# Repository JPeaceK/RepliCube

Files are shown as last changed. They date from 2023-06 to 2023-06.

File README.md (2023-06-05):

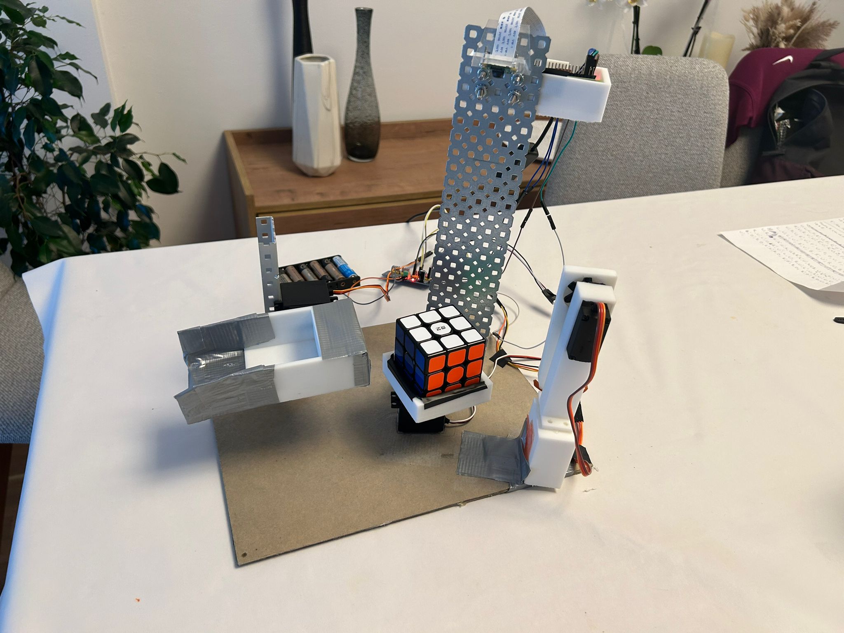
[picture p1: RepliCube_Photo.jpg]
Replicube

# Table of Contents
   * [What is this?](#what-is-this)
   * [Our main goal](#our-main-goal)
   * [Requirements](#requirements)
   * [Documentation](#documentation)
   * [Hardware Structure](hardware-structure)
   * [Software Architecture](software-architecture)
   * [Images](#images)
   * [3D](#3d)
   * [Video](#video)
   * [Special thanks](#special-thanks)
   * [Authors](#authors)

# What is this?
RepliCube is a robot that solves and replicates Rubik Cubes. This robot is equipped with advanced computer vision capabilities that enable it to solve a Rubik's Cube and replicate the pattern of another cube with high accuracy. The robot utilizes a camera to scan and capture the configuration of a Rubik's Cube, which is then stored in its memory for further processing. 

# Our main goal
  
We are a group of 4 students currently studying Computer Engineering at the Universitat Autònoma de Barcelona.  This project is part of a subject called Robòtica, Llenguatge i Programació (RLP), where we are tasked with creating a robot using Agile methods. And our main goal is to bring our 3-month project to life. 

That being said, we hope you enjoy our little project. 

# Requirements
For running code:
 - [Python 3.11.x](https://www.python.org/)

For development:
 - [We used PyCharm](https://www.jetbrains.com/es-es/pycharm/)

# Documentation
All the documentation that might be useful, like servo motors guides, Hardware Structure, or Software Architecture are provided in this repository. The directories that contain this files are named:

 - [Hardware](https://github.com/JPeaceK/RepliCube/tree/main/Hardware)
 - [Software]()
 - [Manual de Fabricantes](https://github.com/JPeaceK/RepliCube/tree/main/Manuales%20de%20Fabricantes)

You can also see the references of the [Hardware Structure](hardware-structure) and the [Software Architecture](software-architecture) in this README.md file.

It is also provided a report that contains all development procedures named "Replicube Report".

# Hardware Structure
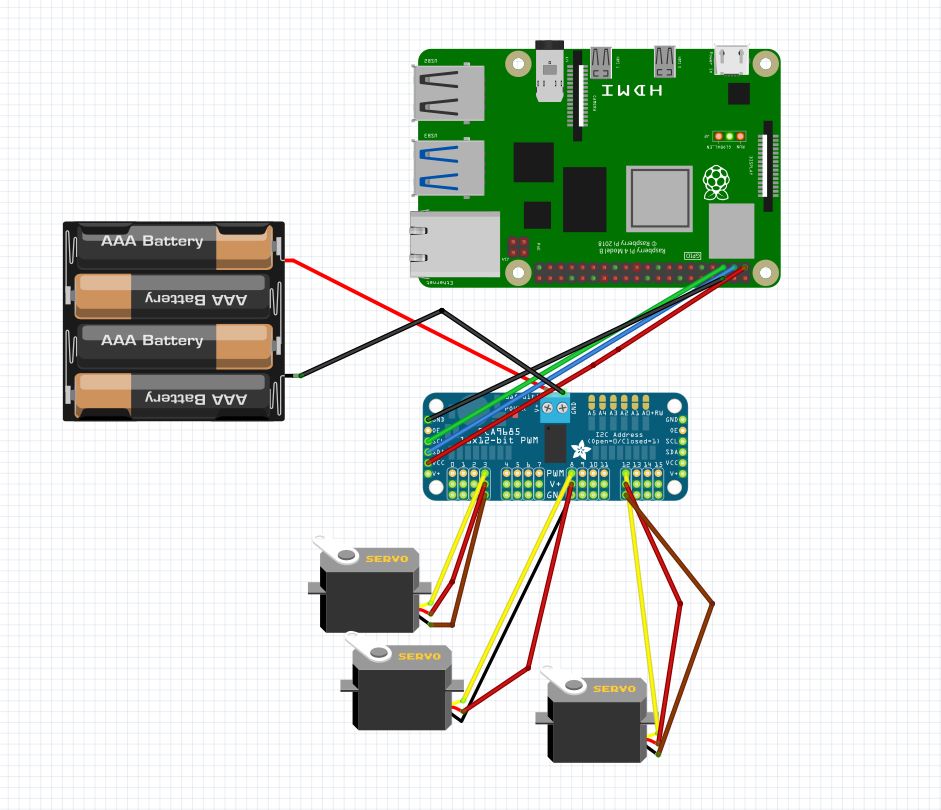
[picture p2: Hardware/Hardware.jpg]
Hardware Structure


# Software Architecture
The software Architecture is the following:
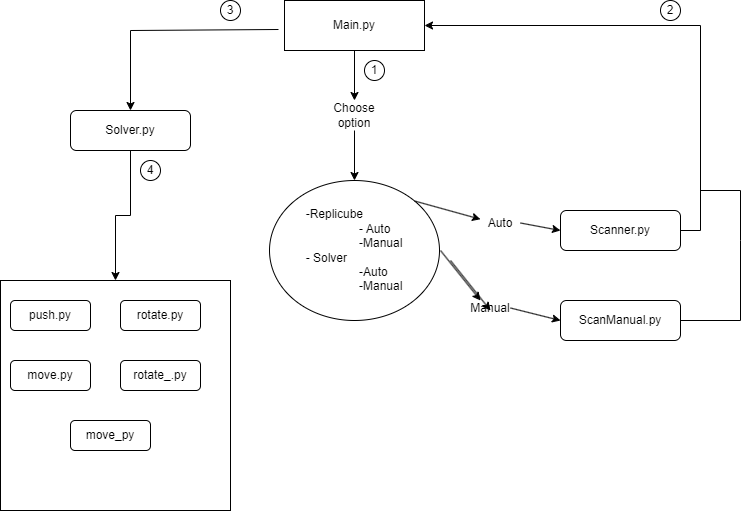
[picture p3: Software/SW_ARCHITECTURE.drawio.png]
Software Structure


And here a Flux Diagram of the code:
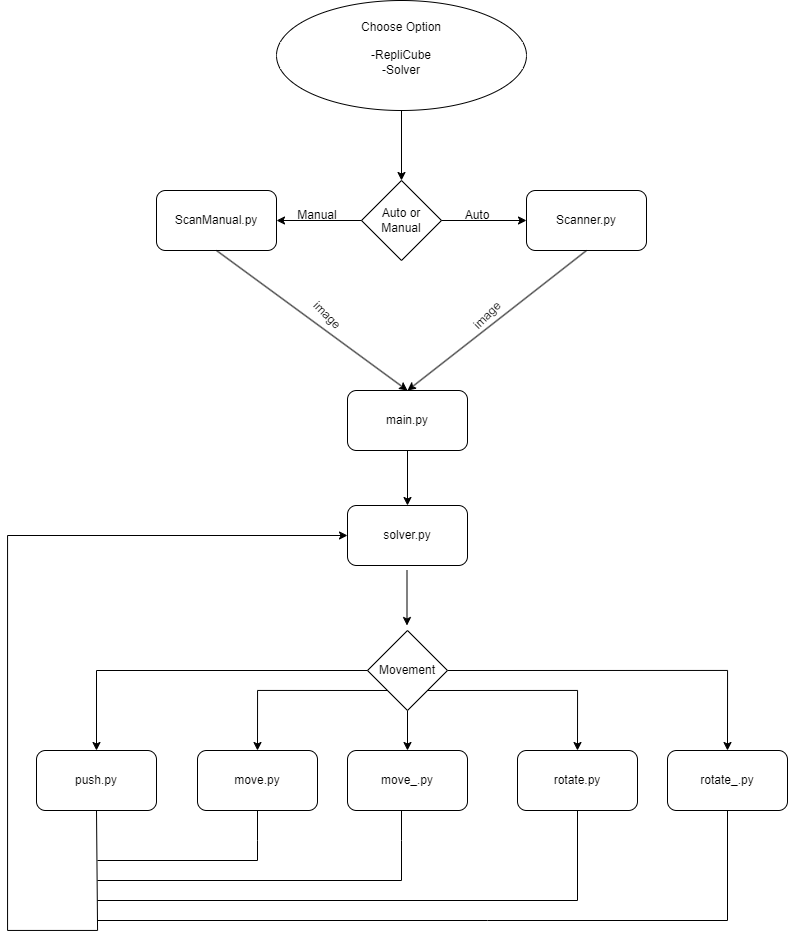
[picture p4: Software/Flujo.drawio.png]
Flux

# Images
You can find a folder named "Images" where all the test images we have used to evaluate our core Computer Vision functionalities are featured. These images have been captured by a Raspberry Pi Camera Module directly connected to the Raspberry Pi 4 Model B.

Here is an example:
Example Image

Ref: (https://github.com/JPeaceK/RepliCube/tree/main/Images)

# 3D
You will also find a folder named "3D" where you can locate all our .stl files that were used in the construction of the robot. This folder includes some pieces that were not ultimately used due to design changes, but we have included them here as they are still part of our project.

Ref: (https://github.com/JPeaceK/RepliCube/tree/main/3D)

# Special thanks
We want to thank our 3 professors from the subject:

 - Fernando Luis Vilariño Freire
 - Carlos Garcia Calvo
 - Vernon Stanley Albayeros Duarte

Thanks to their support, this project has been able tu surpass all it's ups and downs and successfully come to fruition. We are grateful for the support and guidance provided by our professors throughout this project. During critical moments, they offered their expertise and insights, enabling us to find effective solutions.

# Video
https://youtu.be/xmQAyfgD7hg

# Authors
- Joel Paz Cepero
- Gabriel Bardají Biescas
- Pau Carracelas Expósito
- Víctor Valero Carrasco

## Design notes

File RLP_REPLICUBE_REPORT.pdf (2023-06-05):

RLP - Computer Engineering. UAB (Barcelona) 2022-2023

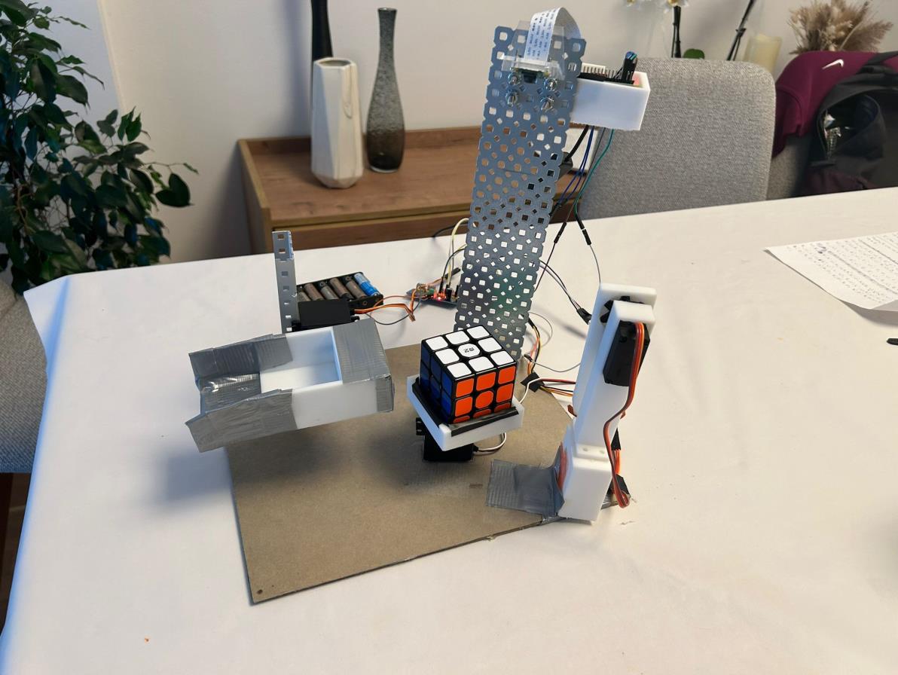
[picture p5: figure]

# REPLICUBE

The robot that solves and replicates Rubik Cubes.

PROJECT Report.
DATE: 05 June 2023

Joel Paz Cepero
Gabriel Bardají Biescas
Pau Carracelas Expósito
Víctor Valero Carrasco

RepliCube

# Table of Contents

Amazing Contributions | 6-7
Extra Components and 3D pieces | 8-12
Foreseen risks and contingency plan | 13-15
Updates Sprint 5 | 15-16
Updates Sprint 6 | -16

RepliCube

# REPLICUBE

The robot that solves and replicates Rubik cubes

Project description
This robot is equipped with advanced computer vision capabilities that enable it to solve a Rubik's Cube and replicate the pattern of another cube with high accuracy. The robot utilizes a camera to scan and capture the configuration of a Rubik's Cube, which is then stored in its memory for further processing.

Using sophisticated image processing algorithms, the robot analyzes the captured data to identify the current state of the Rubik's Cube, including the position and orientation of each colored cubelet. It then employs an efficient solving algorithm to calculate and execute the optimal sequence of moves to solve the cube.

In addition to solving the Rubik's Cube, this robot also has the unique ability to copy the pattern of another cube and replicate it. It uses its computer vision capabilities to scan and capture the pattern of the target cube, and stores the information in its memory.

The robot then uses its solving algorithm to calculate the sequence of moves required to replicate the pattern on its own cube, and executes the moves to recreate the pattern with precision.

RepliCube

Electronic components
This is the list of the proposed components:

■ Raspberry Pi 4 Model B x 1

■ DF15RSMG 360 Degree Motor x1

■ POWERHD 6001HB Analog Servo x1

■ SPRINGRC SM-S4303R Motor CC x1

■ Cámera 5MP OV5647 x 1

■ Raspberry Pi official micro usb x 1

■ PCA9685 Servo’s controllers x1

■ Bateria x6 pilas AA x1


RepliCube

Software Architecture

Our
software architecture is led by a main program in which we have a menu where we decide to solve or replicate the cube. This main program also calls the resolution algorithm and also the Computer Vision one. This last one is only called if we decide to scan the cube automatically instead of manually in the initial display(menu) of the main program. What we do in the scanning phase independently of the option we’ve chosen is, tell our program which is the color that we have in every “mini” square for all the 6 faces of the cube.
On the other hand, what concerns the solver algorithm, what we do is the different types of moves that exist for a cube in which we involve the few different moves we do with our robot (push, rotate, rotate_ (“_” invert side), move, move_). We have to do this because the moves that we can do with the robot are more limited than the ones we can do with our hands. What push does is move forward the cube so we can reach the face that is positioned frontally. If we do this various times we can get “down” and “back” faces too. Rotate moves the whole cube to one side or another. And move, holds the cube and only rotates the base, also, as rotate, to one side, or another.

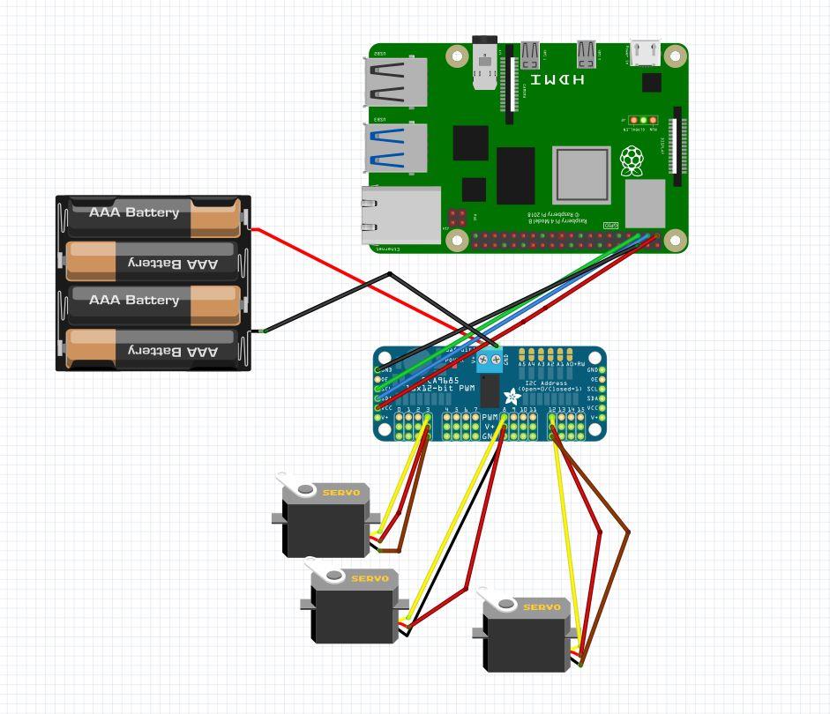
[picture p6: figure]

RepliCube

Hardware Structure

Amazing contributions
1 - Dual functionality: Replicube's ability to both solve a Rubik's cube and replicate the pattern of another cube is a unique feature that sets it apart from other Rubik's cube-solving robots. This dual functionality adds versatility and practicality to the robot.

2 - Advanced solving algorithms: Replicube uses advanced algorithms to determine the most efficient solution for solving or replicating the Rubik's cube patterns. These algorithms enable the robot to operate quickly and accurately

RepliCube

3 - User interface: Replicube's LCD screen and button controls provide a user-friendly interface, allowing users to select the desired functionality and monitor the robot's progress during operation.

4 - Compact design: Utilizing a Raspberry Pi 4 Model B, Replicube is able to maintain a small form factor while still delivering powerful computational capabilities. This compact design allows for easy transport and use in various settings.

5 - Modular design: The modular design of Replicube allows for easy upgrades and modifications, such as adding new features or improving existing components. This adaptability makes the robot suitable for various applications and user preferences.

6 - Advanced computer vision capabilities: One amazing contribution of this project is the development of a robot with advanced computer vision capabilities. By utilizing a camera and sophisticated image processing algorithms, the robot is able to scan, capture, and analyze the configuration of a Rubik's Cube with high accuracy. This breakthrough in computer vision technology enables the robot to understand the current state of the cube, including the position and orientation of each colored cubelet.

Replicube, the dual-function robot capable of solving and replicating Rubik's cube patterns, deserves a high score of 9 due to its innovative features and impressive capabilities. With computer vision as a new technology for the team, the project showcases the ability to adapt and incorporate cutting-edge techniques. The algorithmic complexity of the project demonstrates advanced problem-solving and adaptability, making it an impressive achievement.

The project's purpose is eye-catching and innovative, setting it apart from other robotics projects. Its compact design, enabled by the use of a Raspberry Pi 4 Model B and other carefully selected components, makes Replicube both portable and versatile. Furthermore, the project is budget-conscious, successfully fitting within the allocated 100-euro budget without compromising on functionality or quality.

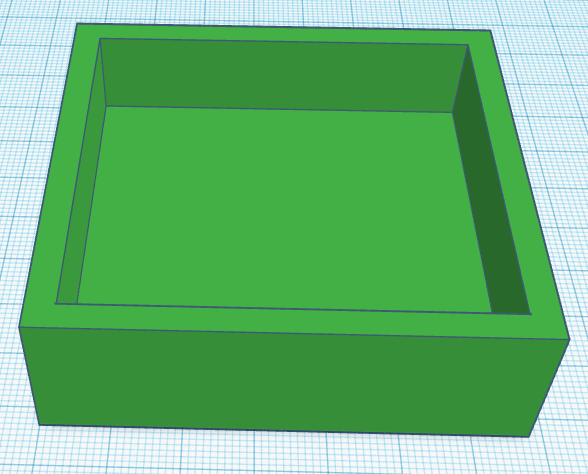
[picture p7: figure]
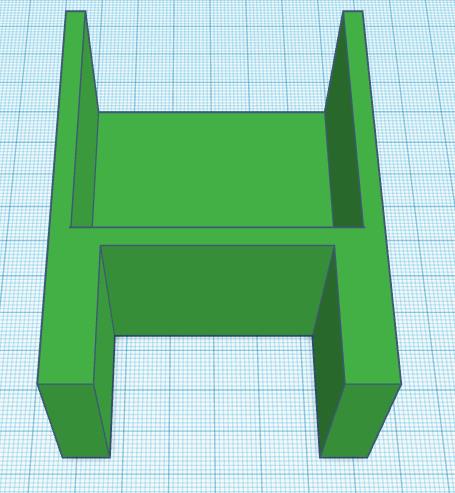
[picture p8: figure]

RepliCube

Extra components and 3D pieces ■ BASE

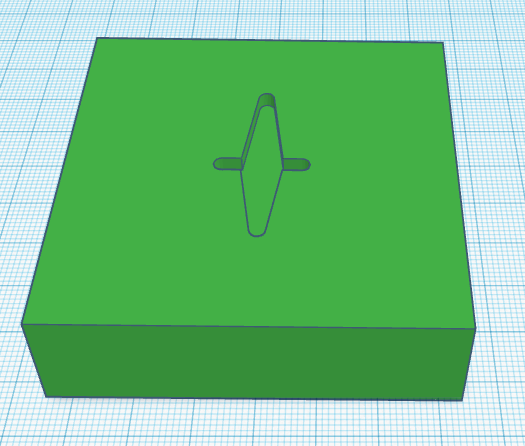
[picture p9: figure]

This piece will be the support for the Rubik's cube. On the bottom, it has a hole where the servo motor will be connected, and it will rotate, changing the state of the cube.

■ CUBE-HOLDER

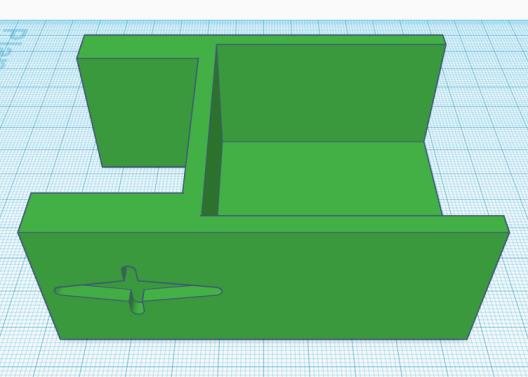
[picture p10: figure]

This piece will be responsible for holding the top part of the cube immobilized while the base rotates and moves the cube to the next state. On one side, it will have a hole that will fit with a servo motor which will rotate the piece 180º to hold or release the cube.

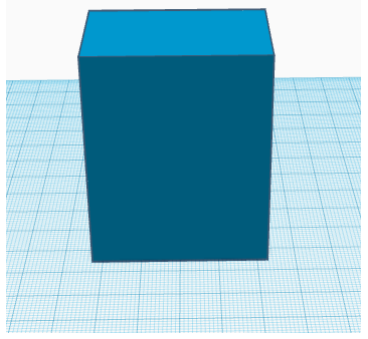
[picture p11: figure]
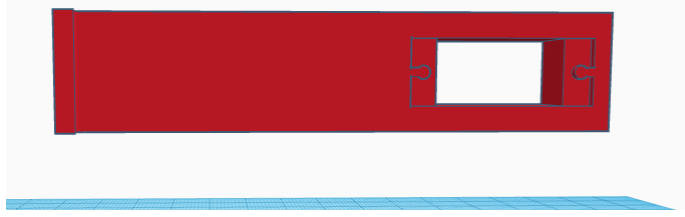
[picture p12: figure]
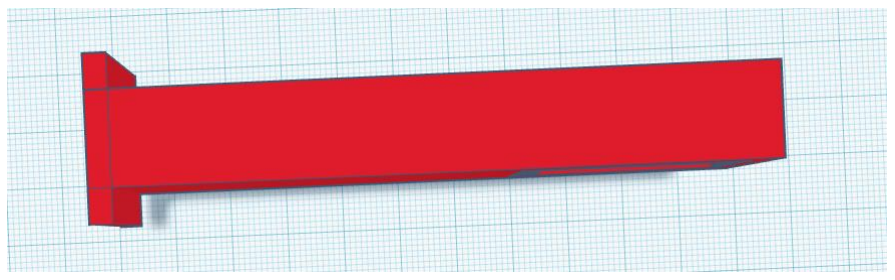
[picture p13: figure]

RepliCube

■ BASE-KNOCKER

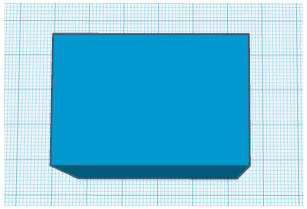
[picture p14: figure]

This piece will be attached to the base of the robot, and its main function will be to provide support for another 3D piece, named the Knocker.

■ SERVO-HOLDER-KNOCKER

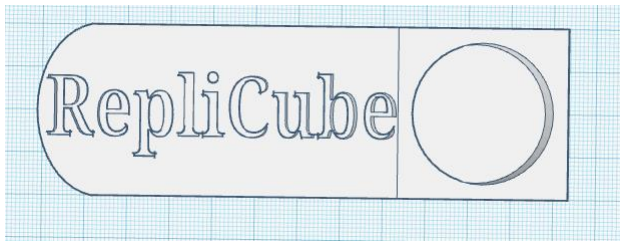
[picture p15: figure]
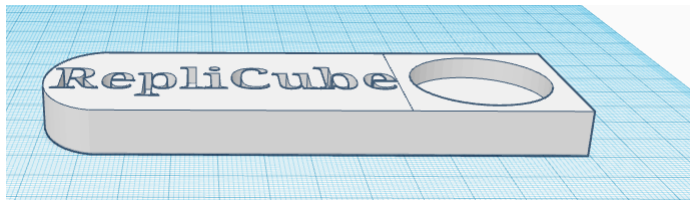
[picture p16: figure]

RepliCube

This piece will contain a servo motor inside, which will be responsible for rotating the Knocker. It will be attached to the previously mentioned 'BASE-KNOCKER' piece.

■ KNOCKER

This piece will be attached to a servo motor and its main function will be to knock the Rubik's Cube, flipping it 90 degrees. It also features the Robot's name.

■ RASPY-HOLDER

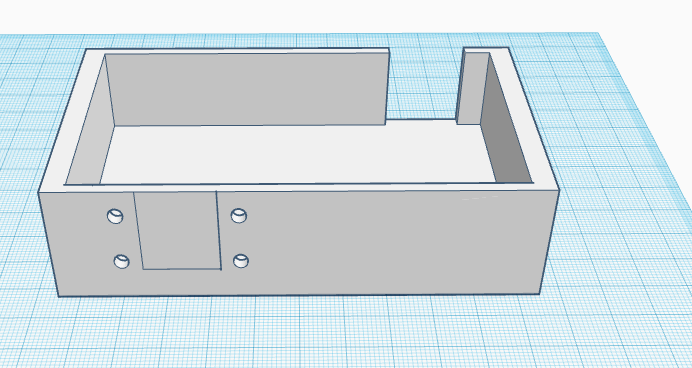
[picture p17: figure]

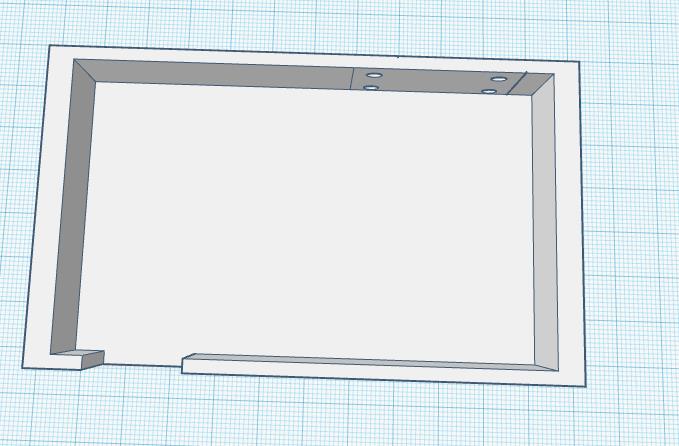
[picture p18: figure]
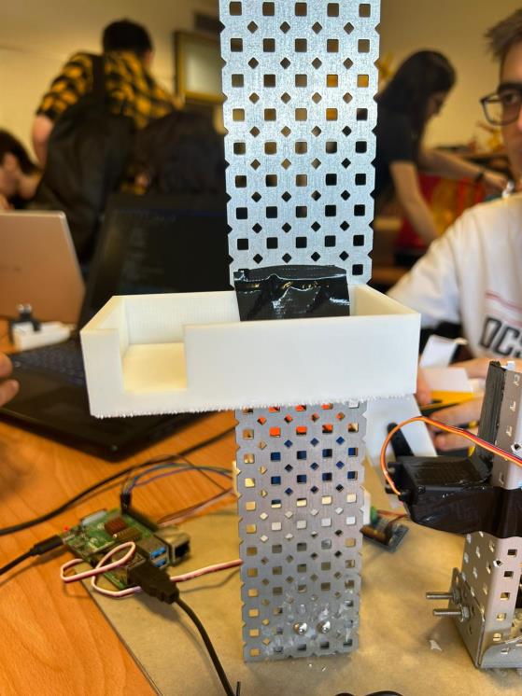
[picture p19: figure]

RepliCube

This piece will be attached to a support and will hold the Raspberry Pi 4 Model B. It is a necessary component because the camera cable is too short.

■ PIECE THAT HOLDS THE CAMERA AND THE RASPY-HOLDER

This piece is attached to the base, and holds the Raspy-Holder and the camera.

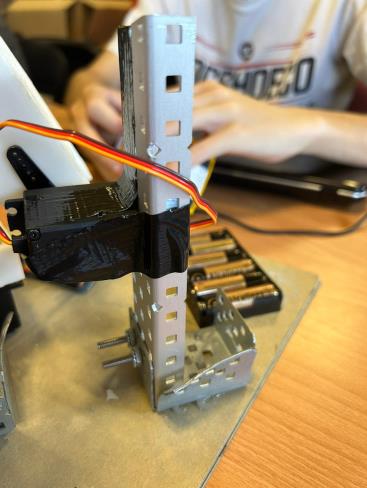
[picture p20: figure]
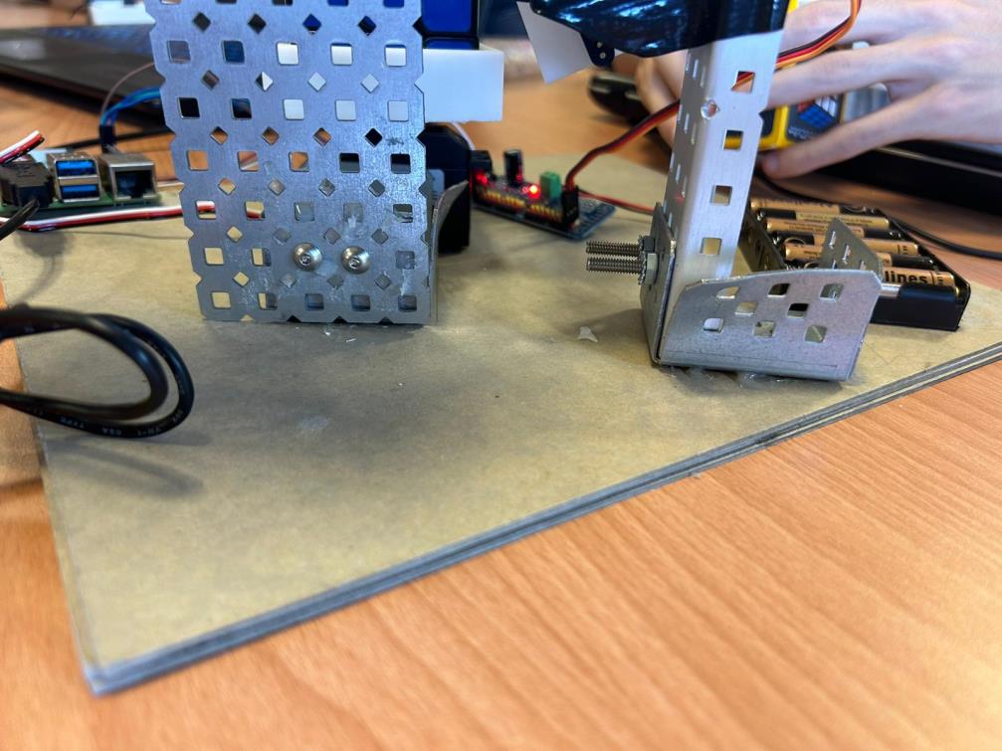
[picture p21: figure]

RepliCube

■ PIECE THAT HOLDS A SERVO

This piece holds a servo motor and it is attached to the base too.

■ Robot base

This is the base of the robot, its design makes it easy to transport and very light.

RepliCube

Strategy for validation, testing and simulation
First of all we will validate the computer vision part, because it’s the key element of the project. It can be done by doing some recognition tests by checking the output that we got and what we expected.

Secondly, we have to test the solving algorithm. This can be done internally without requiring the robot by simulations in a computer.

Then we have to make a simulation of the robot in a simulation software like CoppeliaSim or something related.

We have to also test the replication pattern like the solving pattern.

Foreseen risks and contingency plan
Risk # | Description | Probabilit y (High/Me dium/Low ) | Impact (High/M edium/L ow) | Contingency plan
1 | Accurately replicating the pattern of another cube may face challenges in the precision and alignment of movements to recreate the exact pattern | Medium | Medium | Use a precise calibration methodology to ensure the alignment and precision of the replication movements.
2 | Complexity in Solving Algorithm Developmentin Solving Algorithm Development Designing and implementing an | High | High | Perform extensive tests on different cube configurations to identify and fix potential bugs in the algorithm

RepliCube

| efficient algorithm to solve the Rubik's Cube can be complex and require iterative testing and tuning
3 | The computer vision system may face challenges in accurately and reliably reading the cube configuration, including misidentification of colors or lighting issues. | Medium | High | Have a manual validation process to verify and correct the cube configuration in case of errors.
4 | The CC motor, and de 360 servo may cause little errors that may lead to major errors solving or replicating the cube. | High | Low | We will conduct trial and error tests to minimize this persistent error. We need to ensure that it can perform numerous movements without any noticeable errors
5 | The robot may encounter hardware malfunctions or failures, such as the camera malfunctioning or the motors experiencing issues. | Medium | High | Implement regular maintenance and testing procedures to identify and address potential hardware issues.
6 | Environmental factors, such as changes in lighting conditions or | Medium | Medium | Conduct thorough testing in various environments.

RepliCube

physical obstacles,
may affect the
robot's ability to
accurately perceive
and interact with
the Rubik's Cube

Updates Sprint 2
- All main 3D pieces have been printed.
- Solver algorithm has been implemented.
- Budget has been updated (we realized we had insufficient budget).
- PC design of the project with the main connections has been completed.
- Non-electronic components have been selected.
- GitHub has been created.

Updates Sprint 3
- Computer Vision algorithm has been created, but it has not been tested yet.
- All 3D pieces have been printed and are ready for testing.
- Code has been developed to test all hardware components.
- Raspberry Pi operating system has been installed.
- Code for testing components has been created.
- Hardware Structure diagram created.

Updates Sprint 5
- All hardware components tested.
- Tests to mark where the components must be.
- Unitary tests to determine if we need other components.
- The robot has been assembled.
- Test all connections and motors are tested separately.
- GitHub updates

RepliCube

- Software Architecture diagram created.
- All major components have been received.

Updates Sprint 6
- Robot has been assembled.
- GitHub has been updated.
- Starting with unitary tests.
- Change from Raspberry Pi Zero to a Raspberry Pi 4 Model B.
- Added a new 3D component to support the Raspberry and the camera.
- Requested a PCA9685 servo controller to control the movement.
- Tested a few movements from the solver algorithm.

Updates Sprint 7
- Main functionalities are now implemented.
- Final video recorded and edited.
- GitHub finished.
- README.md file written.
- Final presentation prepared.

RepliCube

# References

Our GitHub project:

https://github.com/JPeaceK/RepliCube

This project has been inspired by the following Internet projects:

https://github.com/judith1304/Arduino-Rubiks-Cube-Solving-Robot

https://github.com/MohammadMouadi/Rubiks-Cube-Solver-Using-Arduino

https://projecthub.arduino.cc/hbolanos2001/6233e259-1629-458c-9f19-f8e9321a3060

https://rlpengineeringschooluab2018.wordpress.com/2018/05/30/rustic-rubiks-solver/ (https://rlpengineeringschooluab2018.wordpress.com/2018/05/30/rustic-rubiks-solver/)

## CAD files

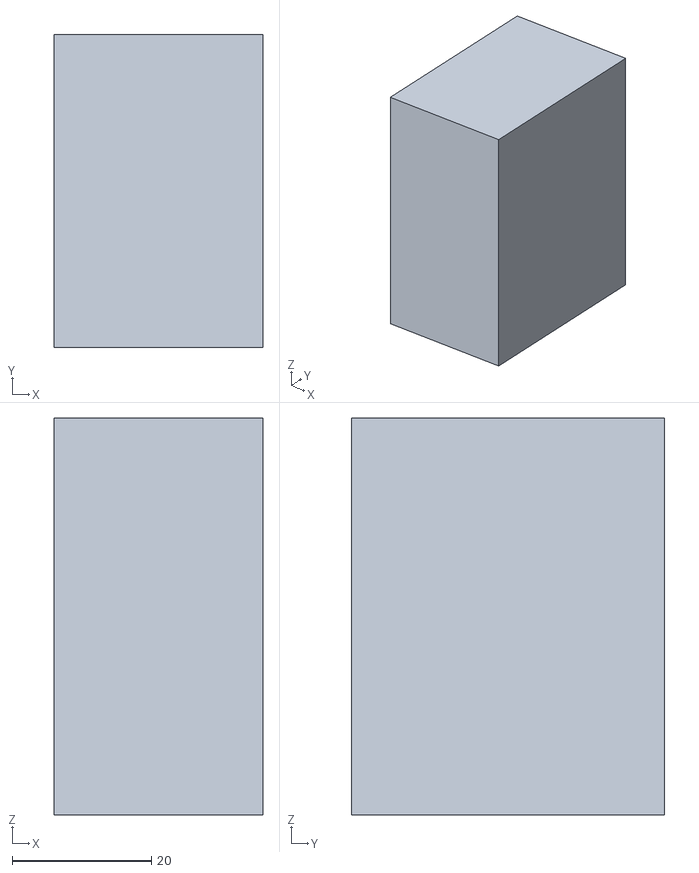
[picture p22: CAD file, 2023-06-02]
3D/Cubo vacio (1).stl
30.0 x 45.0 x 57.0

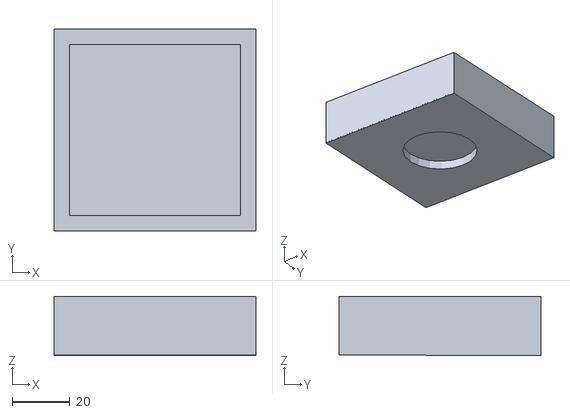
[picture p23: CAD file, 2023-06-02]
3D/base_servo_circular.stl
70.0 x 70.0 x 20.6

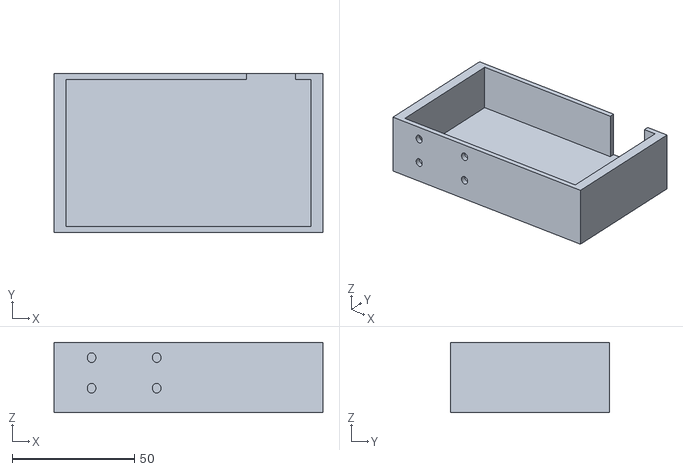
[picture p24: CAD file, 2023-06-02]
3D/base raspy (1).stl
110.0 x 65.0 x 28.7

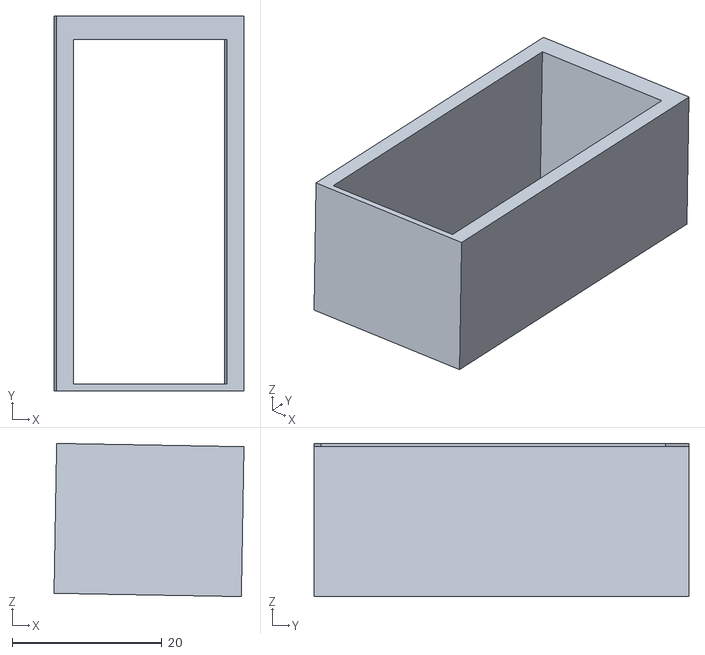
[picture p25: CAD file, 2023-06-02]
3D/Pruebo servo support.stl
25.3 x 50.0 x 20.4

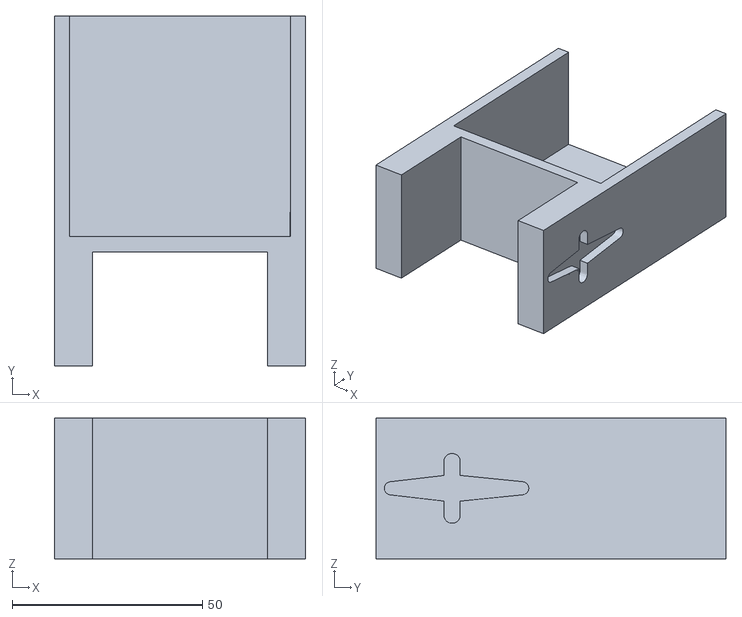
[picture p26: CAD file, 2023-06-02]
3D/holder (1).stl
66.0 x 92.0 x 37.0

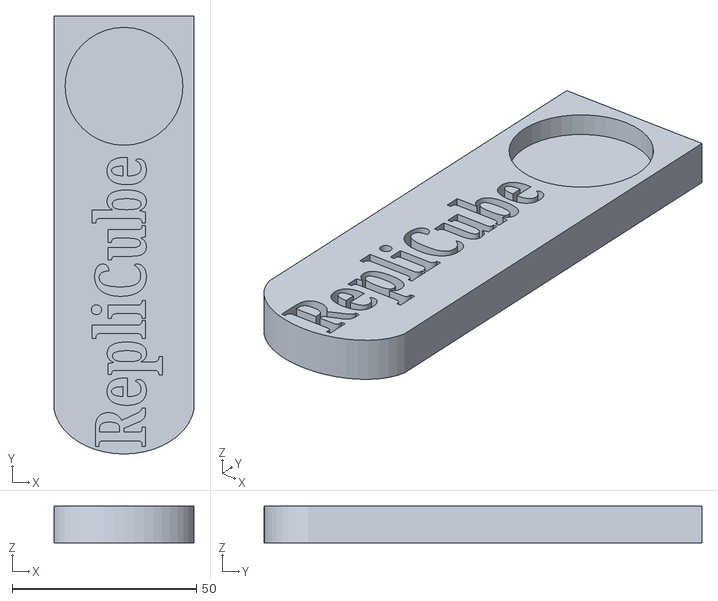
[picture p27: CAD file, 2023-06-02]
3D/Push With letters (2).stl
38.0 x 119.0 x 10.0

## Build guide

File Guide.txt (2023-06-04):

#Conectarnos ssh a raspberry pi zero V1.1
ssh pi2@192.168.149.28 #Si no sabemos la ip de la raspberry, hacemos arp -a
#Nos podemos conectar también con pi2@pi2
@Cotraseña: 1234 o 12345

#Configurar la camera
sudo raspi-config
Seleccionar Interfacing Options
selecciona "Camera" (Cámara) y presiona Enter.
Selecciona "Yes" (Sí) y presiona Enter.
Finish
Sudo reboot

#Para saber la IP de la raspby una vez ya estás dentro para decir cómo conectar a alguien que no tiene la ip:
hostname -I

#Para hacer fotos (desde ssh)
raspistill -o Images/prueba.jpg

#Para descargar la foto (desde cmd de windows)
scp pi2@192.168.149.28:Images/prueba.jpg W:\Escritorio\RepliCube\Images
#También funciona el siguiente, en caso de tenerlo ya configurado
scp pi2@pi2:Images/prueba.jpg W:\Escritorio\RepliCube\Images

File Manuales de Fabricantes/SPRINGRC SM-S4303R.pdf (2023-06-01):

# SPRINGRC SM-S4303R

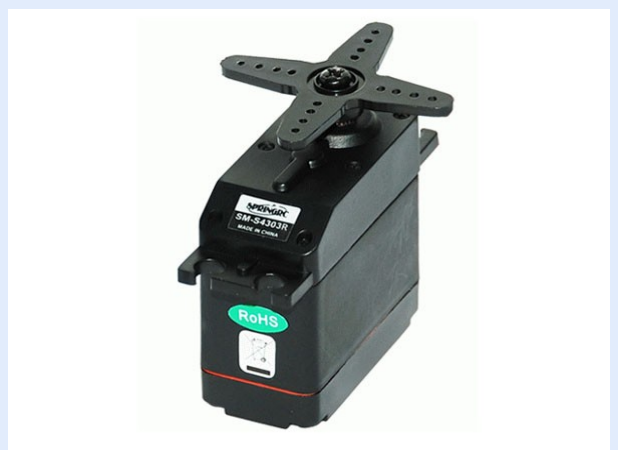
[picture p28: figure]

Products specification | Technical parameters
Size (mm) | Weight | Wire
4.8V | 6V | Rotation angle
Speed | Torque | Speed | Torque
A | B | C | D | E | g | oz | cm | rpm | kg·cm | oz·in | rpm | kg·cm | oz·in
41.3 | 20.7 | 40.2 | 50.3 | 10.0 | 41 | 1.45 | 30.0 | 43 | 3.3 | 45.91 | 54 | 5.1 | 70.95 | 360°
(Specifications are subjected to change without notice.)

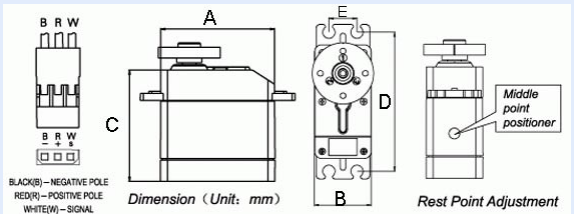
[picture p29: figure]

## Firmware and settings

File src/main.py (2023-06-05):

#THIS IS THE MAIN CODE
from Solver import *
from scanManual import *
import copy
import time
from scanner import *
import cv2


class Cube:
    def __init__(self):
        self.faces = {
            'U': [None, None, None, None, None, None, None, None, None],
            'F': [None, None, None, None, None, None, None, None, None],
            'D': [None, None, None, None, None, None, None, None, None],
            'B': [None, None, None, None, None, None, None, None, None],
            'R': [None, None, None, None, None, None, None, None, None],
            'L': [None, None, None, None, None, None, None, None, None],           
        }

#Cubo con todas las caras resueltas
#Este cubo se utilizará para el algoritmo de resolución
solved = Cube()
solved.faces = {
    'U' : ['B', 'B', 'B', 'B', 'B', 'B', 'B', 'B', 'B'],
    'F' : ['R', 'R', 'R', 'R', 'R', 'R', 'R', 'R', 'R'],
    'D' : ['G', 'G', 'G', 'G', 'G', 'G', 'G', 'G', 'G'],
    'B' : ['O', 'O', 'O', 'O', 'O', 'O', 'O', 'O', 'O'],
    'R' : ['Y', 'Y', 'Y', 'Y', 'Y', 'Y', 'Y', 'Y', 'Y'],
    'L' : ['W', 'W', 'W', 'W', 'W', 'W', 'W', 'W', 'W']
}

#Cubo con el que hacer pruebas
testCube = Cube()
testCube.faces = {
    'U' : ['B', 'B', 'B', 'B', 'B', 'B', 'R', 'R', 'R'],
    'F' : ['W', 'W', 'W', 'G', 'R', 'R', 'G', 'R', 'R'],
    'D' : ['O', 'G', 'G', 'O', 'G', 'G', 'O', 'G', 'G'],
    'B' : ['B', 'O', 'O', 'B', 'O', 'O', 'Y', 'Y', 'Y'],
    'R' : ['G', 'R', 'R', 'Y', 'Y', 'Y', 'Y', 'Y', 'Y'],
    'L' : ['O', 'O', 'B', 'W', 'W', 'W', 'W', 'W', 'W']
}

#Fución que dibuja todas las caras del cubo
def printCube(cube):
    cleanLine = "+-----------+"
    line = "+---+---+---+"
    whiteSpace = "              "

    # Imprime la cara U
    print(f"{whiteSpace}{cleanLine}")
    print(f"{whiteSpace}| {cube.faces['U'][0]} | {cube.faces['U'][1]} | {cube.faces['U'][2]} |")
    print(f"{whiteSpace}{line}")
    print(f"{whiteSpace}| {cube.faces['U'][3]} | {cube.faces['U'][4]} | {cube.faces['U'][5]} |")
    print(f"{whiteSpace}{line}")
    print(f"{whiteSpace}| {cube.faces['U'][6]} | {cube.faces['U'][7]} | {cube.faces['U'][8]} |")
    print(f"{whiteSpace}{cleanLine}")

    #Imprime las caras L, F, R
    print(f"{cleanLine} {cleanLine} {cleanLine}")
    print(f"| {cube.faces['L'][0]} | {cube.faces['L'][1]} | {cube.faces['L'][2]} | | {cube.faces['F'][0]} | {cube.faces['F'][1]} | {cube.faces['F'][2]} | | {cube.faces['R'][0]} | {cube.faces['R'][1]} | {cube.faces['R'][2]} | ")
    print(f"{line} {line} {line}")
    print(f"| {cube.faces['L'][3]} | {cube.faces['L'][4]} | {cube.faces['L'][5]} | | {cube.faces['F'][3]} | {cube.faces['F'][4]} | {cube.faces['F'][5]} | | {cube.faces['R'][3]} | {cube.faces['R'][4]} | {cube.faces['R'][5]} | ")
    print(f"{line} {line} {line}")
    print(f"| {cube.faces['L'][6]} | {cube.faces['L'][7]} | {cube.faces['L'][8]} | | {cube.faces['F'][6]} | {cube.faces['F'][7]} | {cube.faces['F'][8]} | | {cube.faces['R'][6]} | {cube.faces['R'][7]} | {cube.faces['R'][8]} | ")
    print(f"{cleanLine} {cleanLine} {cleanLine}")
    
    #Imprime las caras D, B
    for i in ['D', 'B']:
        print(f"{whiteSpace}{cleanLine}")
        print(f"{whiteSpace}| {cube.faces[i][0]} | {cube.faces[i][1]} | {cube.faces[i][2]} |")
        print(f"{whiteSpace}{line}")
        print(f"{whiteSpace}| {cube.faces[i][3]} | {cube.faces[i][4]} | {cube.faces[i][5]} |")
        print(f"{whiteSpace}{line}")
        print(f"{whiteSpace}| {cube.faces[i][6]} | {cube.faces[i][7]} | {cube.faces[i][8]} |")
        print(f"{whiteSpace}{cleanLine}")


print("Select RepliCube mode:")
print("- 1: Solve cube")
print("- 2: Reply cube")

exit = False
while(not exit):
    user_input = input("Enter your choice: ")
    
    if user_input == "1":
        print("Select scan mode:")
        print("- 1: Auto")
        print("- 2: Manual")
        exit2 = False
        while(not exit2):
            user_input = input("Enter your choice: ")
            if user_input == "1":
                exit2 = True
                cube = Cube()
                scannerMain()
                images = ['CuboU0.jpg', 'CuboU1.jpg', 'CuboU2.jpg', 'CuboU3.jpg','CuboU4.jpg','CuboU5.jpg']
                setColors2(cube, images)

                print("Start solving in...")
                print("3")
                time.sleep(1)
                print("2")
                time.sleep(1)
                print("1")
                time.sleep(1)
                solve(cube, solved)
                
            elif user_input == "2":
                exit2 = True
                cube = Cube()
                cube = copy.deepcopy(solved)
                setColorsManual(cube)
                print("Start solving in...")
                print("3")
                time.sleep(1)
                print("2")
                time.sleep(1)
                print("1")
                time.sleep(1)
                solve(cube, solved)
                
            else:
                print("Invalid choice!")
        exit = True
        
        
        
    elif user_input == "2":
        print("Select scan mode:")
        print("- 1: Auto")
        print("- 2: Manual")
        exit2 = False
        while(not exit2):
            user_input = input("Enter your choice: ")
            if user_input == "1":
                exit2 = True
                cube = Cube()
                scannerMain()
                images = ['CuboU0.jpg', 'CuboU1.jpg', 'CuboU2.jpg', 'CuboU3.jpg','CuboU4.jpg','CuboU5.jpg']
                setColors2(cube, images)
                
                print("Put the second cube inside the box")
                time.sleep(3)
                cubeToReply = Cube()
                scannerMain()
                setColors2(cubeToReply, images)
                
                print("Start replicating in...")
                print("3")
                time.sleep(1)
                print("2")
                time.sleep(1)
                print("1")
                time.sleep(1)
                solve(cube, cubeToReply)
            elif user_input == "2":
                cube = Cube()
                setColorsManual(cube)
                
                cubeToReply = Cube()
                setColorsManual(cubeToReply)
                
                print("Start replicating in...")
                print("3")
                time.sleep(1)
                print("2")
                time.sleep(1)
                print("1")
                time.sleep(1)
                solve(cube, solved)
            else:
                print("Invalid choice!")
        exit = True
    else:
        print("Invalid choice!")
    

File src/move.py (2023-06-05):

import time

from board import SCL, SDA
import busio

from adafruit_motor import servo
from adafruit_pca9685 import PCA9685

def moveMain():
    i2c = busio.I2C(SCL, SDA)
    pca = PCA9685(i2c, address = 0x41)

    pca.frequency = 50

    holder = servo.Servo(pca.channels[4])
    push = servo.Servo(pca.channels[7])
    base = servo.Servo(pca.channels[0])

    push.angle = 180
    time.sleep(0)
    push.angle = 0
    time.sleep(0)
    push.angle = 90
    time.sleep(0)

    #holder.angle = None
    #base.angle = None

    holder.angle = 0
    time.sleep(1)
    holder.angle = None


    base.angle = 180
    time.sleep(0.16)
    #Antes teníamos ángulo 0 y 0.1 seg
    base.angle = None
    time.sleep(1)

    base.angle = 80
    time.sleep(0.28)
    base.angle = None
    time.sleep(0.2)

    holder.angle = 180
    time.sleep(1)
    holder.angle = None

    base.angle = 100
    time.sleep(0.1)
   # time.sleep(0.003)
    base.angle = None
    #base.angle = 100
    #time.sleep(0.04)
    #base.angle = None
    time.sleep(1)

#moveMain()

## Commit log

2023-05-03 Added Solver.py v0.1
    Este script permite añadir manualmente el estado de un cubo, y mostrarlo por pantalla. Además implementa los movimientos PUSH, ROTATE (horario) y ROTATE (antihorario)
2023-05-12 Rotate && Rotate_ bug fixes
    [Solver.py]
2023-06-01 Guía actualizada & Manuales de servos
2023-06-02 piezas 3d
    [Cubo vacio (1).stl, Pruebo servo support.stl, Push With letters (2).stl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]
2023-06-04 Fotos de prueba script VC
2023-06-04 Hardware Structure
    [Hardware.fzz]
2023-06-04 Añadida carpeta 3D y movido archivos ahi
    [Cubo vacio (1).stl, Pruebo servo support.stl, Push With letters (2).stl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]
